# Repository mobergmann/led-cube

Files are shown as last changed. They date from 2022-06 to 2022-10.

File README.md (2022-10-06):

# led-cube

This repository contains:
1. main program: program that runs on the Pi, loads the configuration, and controls the LEDs
2. editor: program to create configuration by yourself
3. assets: files that are relevant for building the cubes
4. documentation: guide on how to assemble the cube, how to compile and install and use the main program and the editor

The documentation can be found in the `doc` folder.
A good entry point to the documentation is the [`doc/README.md`](./doc/README.md) file.

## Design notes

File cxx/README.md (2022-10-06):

# Main Program

## Dependencies
These dependencies must be installed to compile the project
- libgpiod-dev
- cmake
- g++

## Install
For an installation guide see the [documentation](../doc/README.md#compile--install).

## Pins
### User Pins
A list of pins available to the user.
The order of this list represents the available pins from top to bottom.
- 8
- 7
- 2 (does not work)
- 3 (does not work)
- 4
- 11
- 5
- 6
- 19
- 26
- 16

### Assignment
| Designation | Pin | Power-on Pull | Location |
|---|-----|---|---|
| Datain | 12 | Pull Down | Installed |
| Special Pin | 13 | Pull Down | Built-in |
| Shift Clock | 14 | Pull Down | Built-in |
| Store Clock | 15 | Pull Down | Built |
| Reset Pin | 18 | Pull Down | Built |
| Layer 1 | 20 | Pull Down | Built |
| Layer 2 | 21 | Pull Down | Built |
| Layer 3 | 23 | Pull Down | Built |
| Layer 4 | 24 | Pull Down | Built |
| Layer 5 | 25 | Pull Down | Built |
| Pairing LED | 11 | Pull Down | User Pins |
| Bluetooth Button | 6 | Pull Up | User Pins |
| Next Button | 4 | Pull Up | User Pins |
| Previous Button | 5 | Pull Up | User Pins |
| Power Button | 7 | Pull Up | User Pins |

## Program
### file format
The configurations are in [JSON](https://www.json.org/json-de.html) format.  
Each frame is specified with the time to be displayed.  
The data is specified as a 3D array.

For example, a configurations that causes the cube to light up fully for one second and then remain dark for one second might look like the following:
```json
{
  "frames": [
    {
      "frame-time": 1000,
      "layers": [
        [
          [true, true, true, true, true],
          [true, true, true, true, true],
          [true, true, true, true, true],
          [true, true, true, true, true],
          [true, true, true, true, true]
        ],
        [
          [true, true, true, true, true],
          [true, true, true, true, true],
          [true, true, true, true, true],
          [true, true, true, true, true],
          [true, true, true, true, true]
        ],
        [
          [true, true, true, true, true],
          [true, true, true, true, true],
          [true, true, true, true, true],
          [true, true, true, true, true],
          [true, true, true, true, true]
        ],
        [
          [true, true, true, true, true],
          [true, true, true, true, true],
          [true, true, true, true, true],
          [true, true, true, true, true],
          [true, true, true, true, true]
        ],
        [
          [true, true, true, true, true],
          [true, true, true, true, true],
          [true, true, true, true, true],
          [true, true, true, true, true],
          [true, true, true, true, true]
        ]
      ]
    },
    {
      "frame-time": 1000,
      "layers": [
        [
          [false, false, false, false, false],
          [false, false, false, false, false],
          [false, false, false, false, false],
          [false, false, false, false, false],
          [false, false, false, false, false]
        ],
        [
          [false, false, false, false, false],
          [false, false, false, false, false],
          [false, false, false, false, false],
          [false, false, false, false, false],
          [false, false, false, false, false]
        ],
        [
          [false, false, false, false, false],
          [false, false, false, false, false],
          [false, false, false, false, false],
          [false, false, false, false, false],
          [false, false, false, false, false]
        ],
        [
          [false, false, false, false, false],
          [false, false, false, false, false],
          [false, false, false, false, false],
          [false, false, false, false, false],
          [false, false, false, false, false]
        ],
        [
          [false, false, false, false, false],
          [false, false, false, false, false],
          [false, false, false, false, false],
          [false, false, false, false, false],
          [false, false, false, false, false]
        ]
      ]
    }
  ]
}
```

In the input there must be an attribute of type array, which has the name `frames`.
This holds a set of frame objects.

Each frame object has an integer attribute `frame-time`. This specifies in milliseconds how long the frame should be visible.

In the attribute `layers` is a 3D array, of size 5x5x5.  
The first dimension represents the layers (the layers from bottom to top).
Each layer, thus the second dimension, consists of 5 so-called lines.
Each line consists of 5 boolean values. 
These code whether an LED should be on or off.

The LED at the position 'layers[1][2][3]` thus represents the LED that is in the first layer (from bottom to top), in the second line (from front to back) and in the third position (from left to right).

### Loading configurations
The configuration (the `json` files) that a user wants to display in the cube must be present in the folder `~/.led-cube/custom`.

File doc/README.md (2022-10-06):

# Documentation
This is the documentation for the 3D LED Cube.
Here is documented how to assemble the cube, the assets needed for it, how to compile the program and install it on the cube, how to use the editor, and how to use the cube.

## Assets
For the assembly, a few assets are needed, which are summarized here.

### PCB
In the `assets/PCB` folder is the KiCad files for the PCB. 
You will need to have this made/ordered.

### 3D Print
In the `assets/3D-Print` folder are the STL files for the cube exterior.
You will need to have these printed.

## Assemble
See the [`assemble.md` file](./assemble.md) for more information on how to assemble the cube.

## Main Program
The "Main Program" is the program that runs continuously on the Pi to respond to I/O input from the buttons and to display the current configuration frame by frame.

### Buttons Function
There are several buttons.
- **Sync Button**: The Sync button persistently loads files from an inserted USB stick into the internal memory.
  If files have the same name as files that are already on the cube, they will be overwritten.
  The LED next to the Sync button will blink to indicate how long the transfer will take (this should not take too long).
- **Previous-/ Next Button**: The Previous and Next button toggles between the configurations it has stored.
  Previous toggles back one configuration and Next toggles forward one configuration.
- **On/ Off Button**: Turns off the LEDs, but continues to simulate the frames.
- **Reset Button**: The Reset Button is a special button, whose functionality can only be obtained by pressing the *Sync Button* for a long time - at least 3 seconds.
Then the current configuration is deleted from the persistent storage and the next program is loaded. Only configurations uploaded by the user can be deleted, and pre-installed programs cannot be deleted.

### Compile & Install
To make the installation as easy as possible we have added a few scripts in the `cxx/install/` folder.
1. build script
2. install script

If you dont want to compile the program you can simply download a Release, unzip it into the USB and continue with the *Install* step.

If you want to compile the program yourself you need a Pi with internet access because you have to compile it for the operating system and architecture of the Pi.
You can also compile the code without a Pi with the right tools, but this is relatively complex and will not be explained here.
If you still want to try to compile *without Pi* or *without internet access*, you should know that you need the `libgpiod2` dependency for the *main program* and the `libgpiod-dev` dependency *for compilation*.

#### Build
But if you use the Pi, you can simply clone the repo (with the submodules) and run the `cxx/build/build.sh` script.
Make sure you have a USB stick plugged into the compile pi and confirm during the script if you want the files to be written to the stick with yes.
If your USB stick cannot be found, then it can be because it is not accessible under the `/dev/sda1` path.
In this case, you can change the path from `/dev/sda1` to your path in the script.

#### Install
If you have installed the programs from the build to the USB stick, then you can put the stick into your LED-Cube-Pi.
On the USB you should find a `cube/` folder, where you can also find an `install.sh` file.
You have to execute this file to install the program on the Pi.

The installation also includes the entry and activation as a system service, so that the program starts automatically when the Pi is started.

#### Commands
On the Compile-Pi run:
```bash
git clone --recurse-submodules git@github.com:mobergmann/led-cube.git
cd led-cube/cxx/install
# plug in a USB stick
./build.sh # watch out for I/O
            # enter your (sudo) password
            # press y to install to usb
```

Switch to the Cube-Pi, plug in the prepared USB, and then run:
```bash
mount /dev/sda1 /mnt
cd /mnt/cube
sudo sh install.sh
reboot
```

## Editor
See the [`/editor/README.md` file](../editor/README.md) for more information on how to compile and use the editor.

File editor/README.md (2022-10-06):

# Editor

## Dependencies

[Processing](https://processing.org/download)

[ControlP5](https://www.sojamo.de/libraries/controlP5/)

## Install ControlP5

To install ControlP5. Download ControlP5 and unzip it. Then drag it into the Sketchbook folder of Processing.
After that Processing has to be restarted.

## Program

### Cube / LED Toggle
Individual LEDs can be edited by simply clicking on them. 
The cube can also be rotated by dragging the mouse.

### New Frame
A new empty frame can be created.
This is always created under the currently selected one.

### Copy / Paste Frame
The current frame can be copied and pasted to another location.

### Delete Frame
To delete the current frame

### Frame Time
The time until the next frame can be set here. Default: 1ms

### X / Y / Z
These buttons can be used to move the current frame in one direction.

### Place / Remove RND (Random)
A random LED can be switched off or on with this button.

### Magic Button
In Processing, an individual script can be created for this purpose with which frames can be created automatically. Simply add your code in line 266 in the editor.pde file. 

### Open File
An existing .json file can be selected here. 

### File Name
Here you can edit the name of the file. Files with the same name will be overwritten. To save a file, it must have a name.

### Save File
The file is saved here. A folder must be selected beforehand in which the file will be saved.

### Frame List
Here you can switch back and forth between the individual frames. The currently selected frame is displayed in the head.

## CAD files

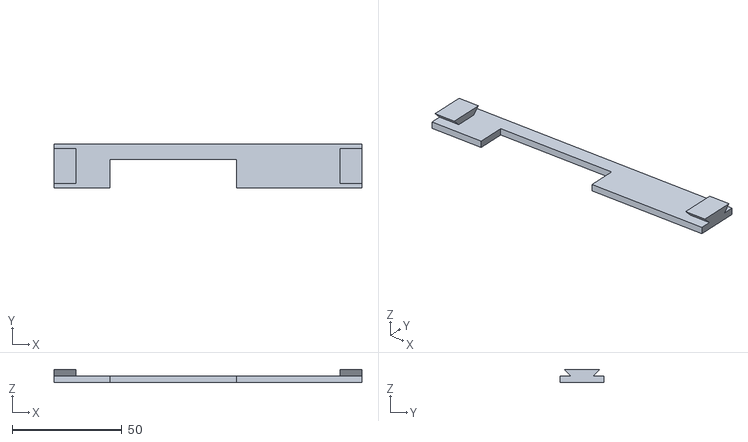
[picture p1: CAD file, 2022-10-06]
assets/3D-Print/right-side.stl
140.0 x 20.0 x 6.00

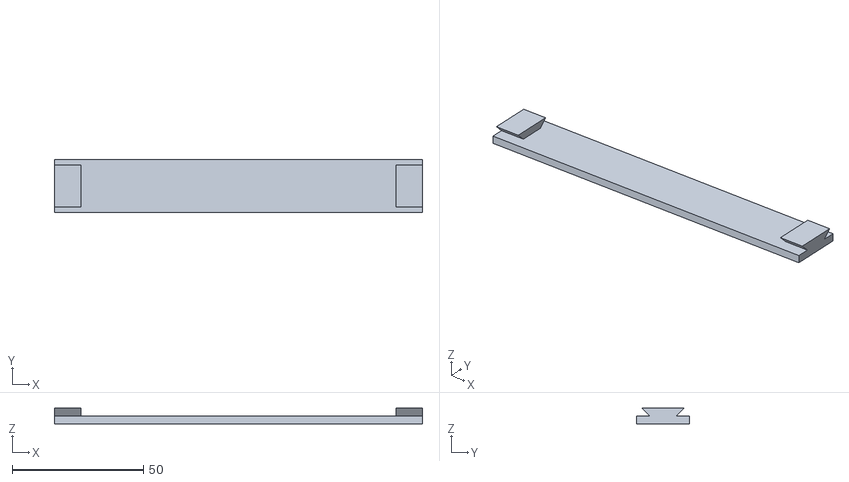
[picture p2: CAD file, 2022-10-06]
assets/3D-Print/left-side.stl
140.0 x 20.0 x 6.00

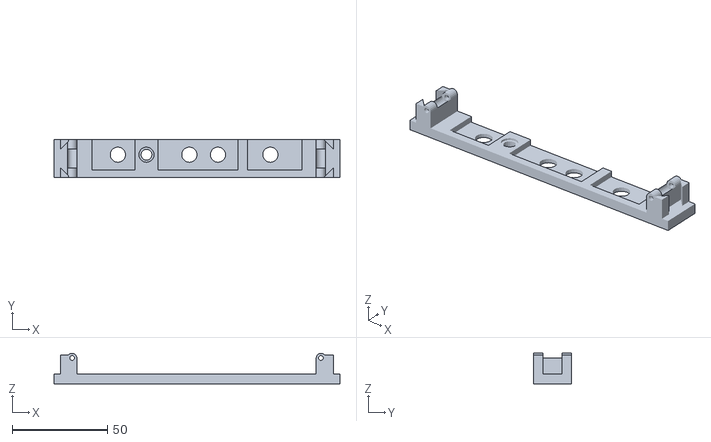
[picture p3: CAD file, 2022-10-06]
assets/3D-Print/front-side.stl
150.0 x 20.0 x 16.0

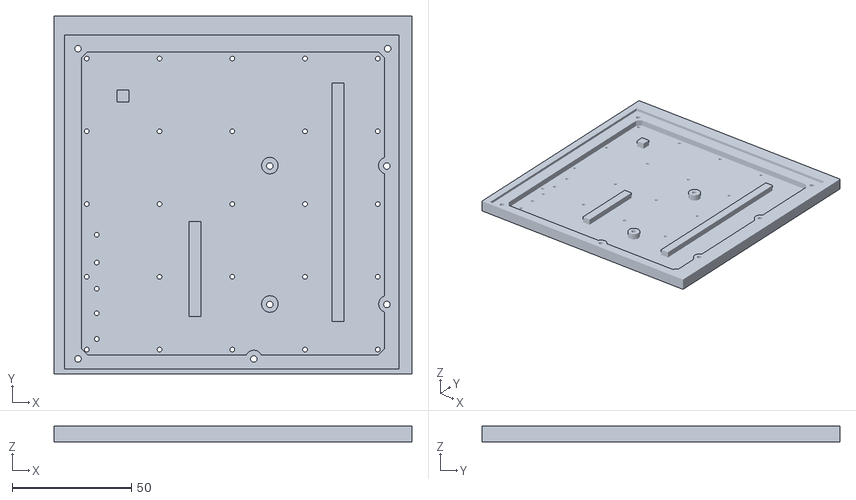
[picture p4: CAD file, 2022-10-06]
assets/3D-Print/top.stl
150.0 x 150.0 x 6.65

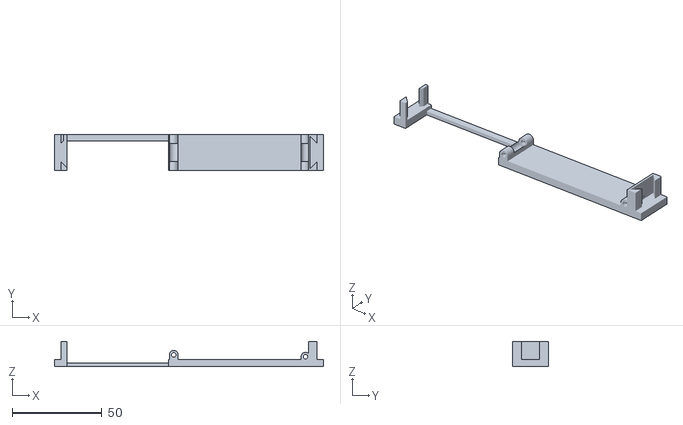
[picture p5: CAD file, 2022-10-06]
assets/3D-Print/back-side.stl
150.0 x 20.0 x 14.0

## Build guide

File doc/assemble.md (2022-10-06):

# Assemble

## Components

- Soldering iron and solder
- vice
- 1x PCB board (plan available in the appendix)
- 1x Raspberry Pi 2 or better
- 1x Micro SD card
- 125x LED 20mA, 3.3V
- 1x LED 20mA, 3.3V (different color)
- 5x rolls of wire 1.0mm
- 25x 100 Ohm resistors
- 5x 1k Ohm resistors
- 1x 10k Ohm resistors
- 3x 74HC595 shift register
- 3x matching sockets
- 3x Ceramic Disk Capacitor 0.1 microfarad
- 1x multilayer ceramic capacitor (MLCC) 220 nanofarad, 50 volts
- 1x Tantalum electrolytic capacitor 2.2 microfarad, 35 volts +
- 5x Transistor 2N2222A H331
- 5x 2N222A transistors
- 1x Female Pinheader 1x14
- 1x Male Pinheader 1x6
- 1x Female Pinheader 2x20
- 1x LF 33 CV voltage converter
- 4x Raspberry Pi spacer
- 3x Brass Spacer M2*20
- 4x Pushbuttons
- 1x plexiglass plate 30cm x 30cm
- 8x M2 screws and nuts
- ribbon cable
- (nail polish)

## Assembly

### PCB

The PCB was designed so that you can usually tell which components go where. 
Additional reference: The components come to the following places

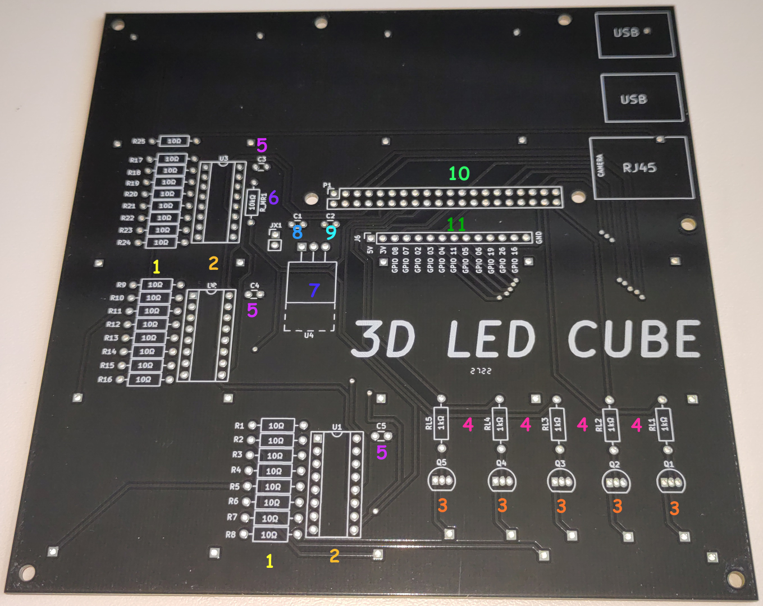
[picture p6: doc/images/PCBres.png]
PCB


1. 100 Ohm resistors
2. 74HC595 shift register and matching sockets
3. 2N222A transistors
4. 1k Ohm resistors
5. Ceramic Disk Capacitor 0.1 microfarad
6. 10k Ohm resistors
7. LF 33 CV voltage converter
8. multilayer ceramic capacitor (MLCC) 220 nanofarad, 50 volts
9. Tantalum electrolytic capacitor 2.2 microfarad, 35 volts +
10. Female Pinheader 2x20 and Raspberry Pi 2
11. Female Pinheader 1x14, Male Pinheader 1x6 for the buttons

### Wire Mesh

The wire mesh consists of 125 LEDs and a lot of wire. Each layer contains 25 LEDs connected with wire. We would recommend using a wood template or something similar. Sold 5 LEDs to a wire, make sure that you only connect the annodes OR cathodes.
Connect the LED-wires with 2 additional wires to form a square. Depending on the used LED, it might be necessary to cover the LEDs bottom with (nail) paint to avoid lower LEDs light shining through. Repeat this step 5 times.
Thread 30 wires through PCB and printed board and solder them to the PCB. Use spacers to ensure even spacing. Sold the remaining annode or cathode to the respective upwards pointing wire.
Each layer needs to be connected with it's corresponding layer wire in the back right. The most left to layer one, the most right wire to the last (upper) layer.
The image in the editor can be used as a reference.

### Buttons

3D print the case and screw the buttons and the "connection LED" to the intended places. Attach a ribbon cable to each button and one of the led wires.
Sold the male pinheader to the other ends of the ribbon cables. Use an additional wire to connect the remaining pins and connect an additional ribbon cable for ground.
Plug the male pinheader in the female pinheader as following:

- black button to GPIO 07
- green button to GPIO 04
- yellow button to GPIO 11
- LED to GPIO05
- blue button to GPIO 06
- ground wire to GND

### Last steps

Use the screws to assemble the case. Use the Plexiglas to seal the case as a see through bottom. The edge of the Plexiglas pane can be worn down so that the light of the Raspberry Pi does not show through.

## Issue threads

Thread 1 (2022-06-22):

pin enabeling is reserved

mobergmann, 2022-06-22:
the order of the pins that are activated is reversed in the main program

mobergmann, 2022-06-22:
@Seb8299 waren nur die pins pro lain verdreht, oder auch die lains?

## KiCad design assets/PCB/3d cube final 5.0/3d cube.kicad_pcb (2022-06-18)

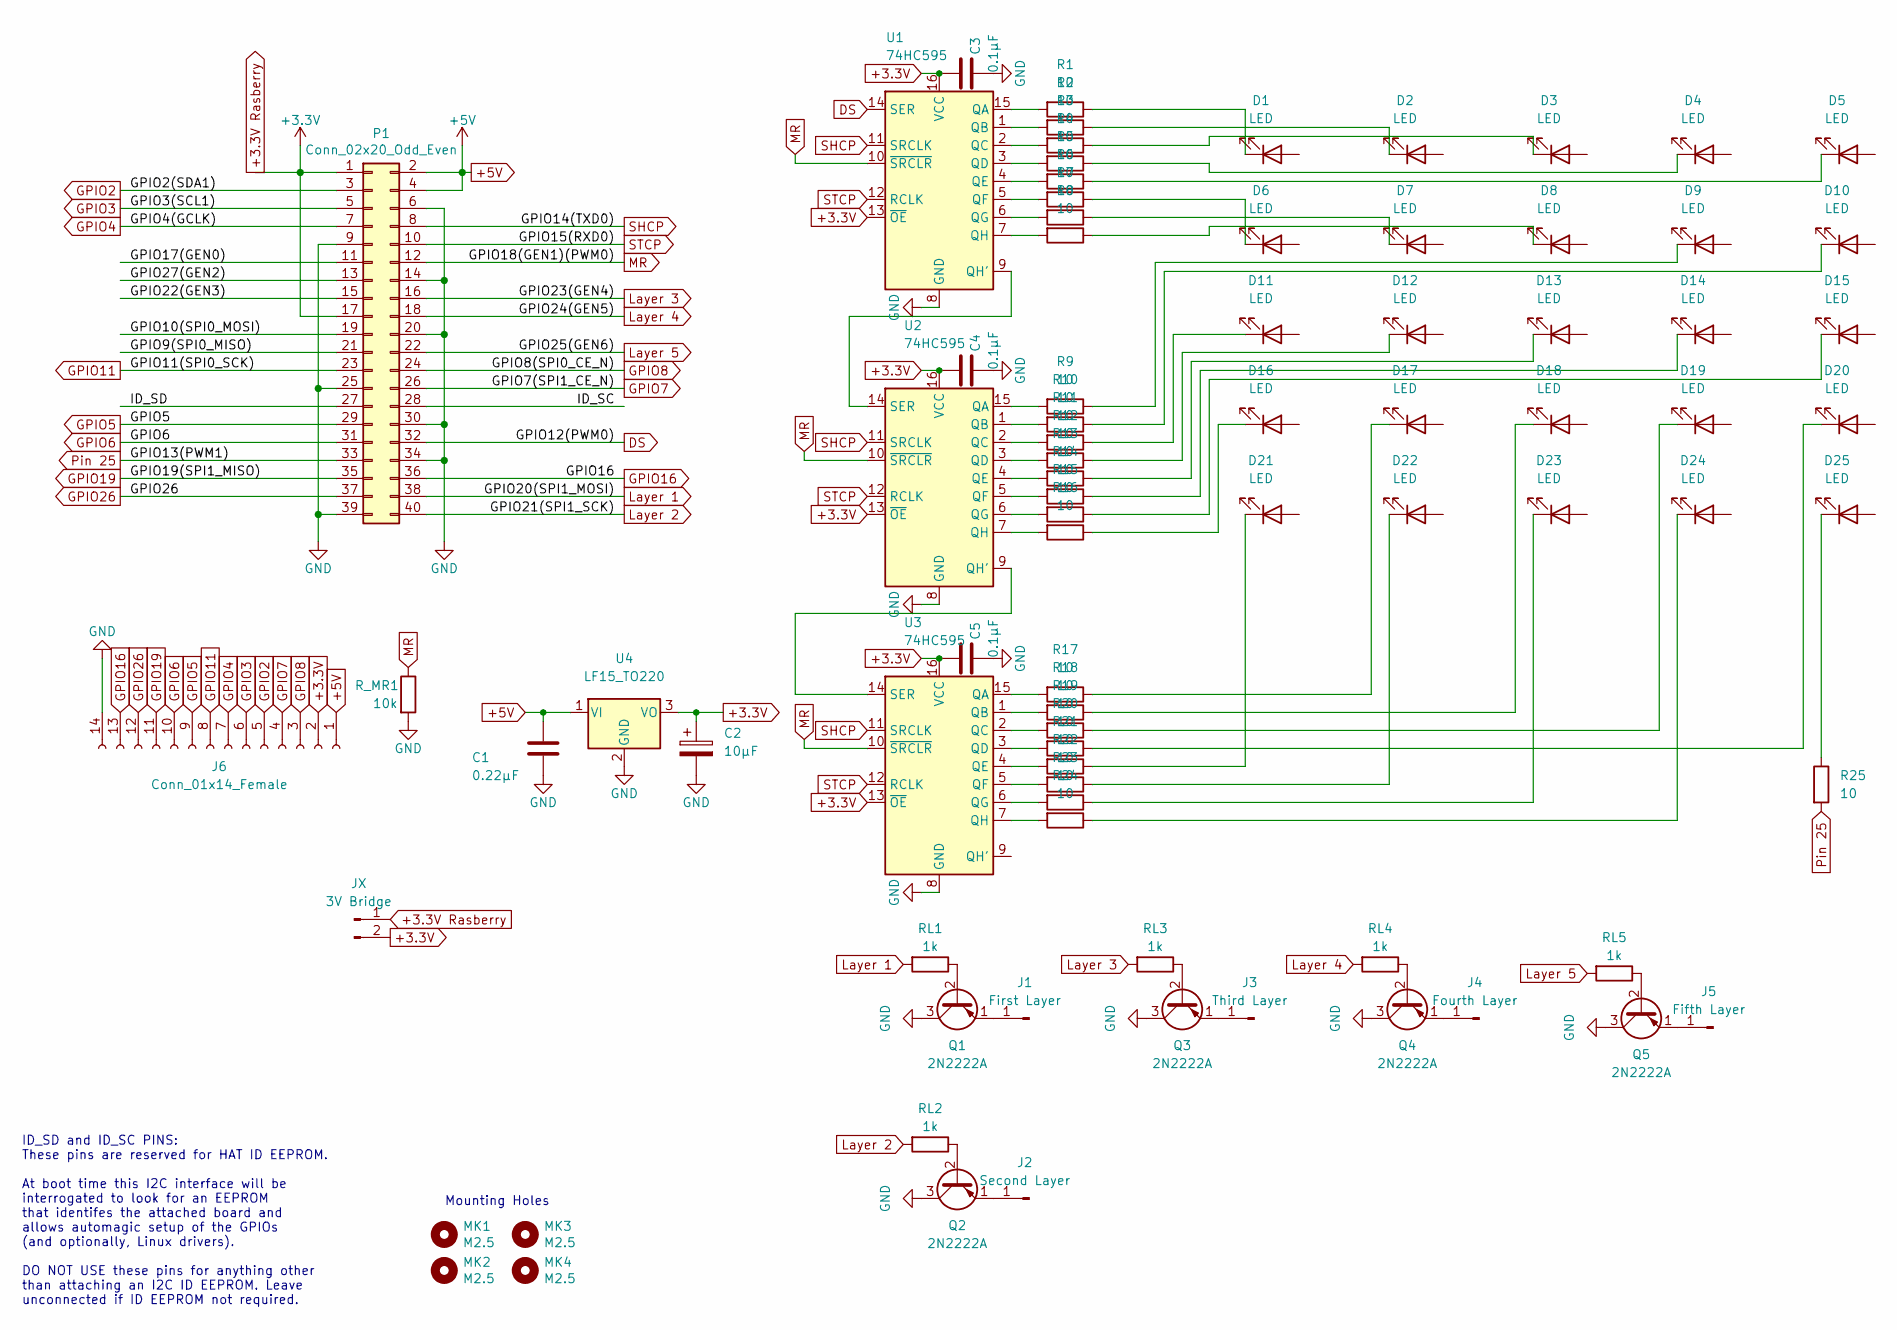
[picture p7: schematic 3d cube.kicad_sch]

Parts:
C1: 0.22μF; C_Disc_D3.0mm_W1.6mm_P2.50mm
C2: 10μF; C_Disc_D3.0mm_W1.6mm_P2.50mm
C3, C4, C5: 0.1μF; C_Disc_D3.0mm_W1.6mm_P2.50mm
D1, D2, D3, D4, D5, D6, D7, D8, D9, D10, D11, D12, D13, D14, D15, D16, D17, D18, D19, D20, D21, D22, D23, D24, D25: LED; PinSocket_1x01_P2.54mm_Vertical
J1: First Layer; PinSocket_1x01_P2.54mm_Vertical
J2: Second Layer; PinSocket_1x01_P2.54mm_Vertical
J3: Third Layer; PinSocket_1x01_P2.54mm_Vertical
J4: Fourth Layer; PinSocket_1x01_P2.54mm_Vertical
J5: Fifth Layer; PinSocket_1x01_P2.54mm_Vertical
J6: Conn_01x14_Female; PinSocket_1x14_P2.54mm_Vertical
JX: 3V Bridge; PinHeader_1x02_P2.54mm_Vertical
MK1, MK2, MK3, MK4: M2.5; MountingHole_2.7mm_M2.5
P1: Conn_02x20_Odd_Even; PinSocket_2x20_P2.54mm_Vertical
Q1, Q2, Q3, Q4, Q5: 2N2222A; TO-92_Inline
R1, R2, R3, R4, R5, R6, R7, R8, R9, R10, R11, R12, R13, R14, R15, R16, R17, R18, R19, R20, R21, R22, R23, R24, R25: 10; R_Axial_DIN0207_L6.3mm_D2.5mm_P10.16mm_Horizontal
RL1, RL2, RL3, RL4, RL5: 1k; R_Axial_DIN0207_L6.3mm_D2.5mm_P10.16mm_Horizontal
R_MR1: 10k; R_Axial_DIN0207_L6.3mm_D2.5mm_P10.16mm_Horizontal
U1, U2, U3: 74HC595; DIP-16_W7.62mm_Socket
U4: LF15_TO220; TO-220-3_Horizontal_TabUp

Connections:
+3.3V: C2.1, C3.1, C4.1, C5.1, J6.2, JX.2, U1.13 (~OE), U1.16 (VCC), U2.13 (~OE), U2.16 (VCC), U3.13 (~OE), U3.16 (VCC), U4.3 (VO); also elsewhere on the board
+3.3V Rasberry: JX.1, P1.1, P1.17; also elsewhere on the board
+5V: C1.1, J6.1, P1.2, P1.4, U4.1 (VI)
/GPIO9(SPI0_MISO): P1.21
/GPIO10(SPI0_MOSI): P1.19
/GPIO17(GEN0): P1.11
/GPIO22(GEN3): P1.15
/GPIO27(GEN2): P1.13
/ID_SC: P1.28
/ID_SD: P1.27
DS: P1.32, U1.14 (SER)
GND: C1.2, C2.2, C3.2, C4.2, C5.2, J6.14, P1.6, P1.9, P1.14, P1.20, P1.25, P1.30, P1.34, P1.39, Q1.3 (C), Q2.3 (C), Q3.3 (C), Q4.3 (C), Q5.3 (C), R_MR1.2, U1.8 (GND), U2.8 (GND), U3.8 (GND), U4.2 (GND)
GPIO2: J6.5, P1.3
GPIO3: J6.6, P1.5
GPIO4: J6.7, P1.7
GPIO5: J6.9, P1.29
GPIO6: J6.10, P1.31
GPIO7: J6.4, P1.26
GPIO8: J6.3, P1.24
GPIO11: J6.8, P1.23
GPIO16: J6.13, P1.36
GPIO19: J6.11, P1.35
GPIO26: J6.12, P1.37
Layer 1: P1.38, RL1.2
Layer 2: P1.40, RL2.2
Layer 3: P1.16, RL3.2
Layer 4: P1.18, RL4.2
Layer 5: P1.22, RL5.2
MR: P1.12, R_MR1.1, U1.10 (~SRCLR), U2.10 (~SRCLR), U3.10 (~SRCLR)
unnamed: D1.1 (K), R1.1
unnamed: D2.1 (K), R2.1
unnamed: D3.1 (K), R3.1
unnamed: D4.1 (K), R4.1
unnamed: D5.1 (K), R5.1
unnamed: D6.1 (K), R6.1
unnamed: D7.1 (K), R7.1
unnamed: D8.1 (K), R8.1
unnamed: D9.1 (K), R9.1
unnamed: D10.1 (K), R10.1
unnamed: D11.1 (K), R11.1
unnamed: D12.1 (K), R12.1
unnamed: D13.1 (K), R13.1
unnamed: D14.1 (K), R14.1
unnamed: D15.1 (K), R15.1
unnamed: D16.1 (K), R16.1
unnamed: D17.1 (K), R17.1
unnamed: D18.1 (K), R18.1
unnamed: D19.1 (K), R19.1
unnamed: D20.1 (K), R20.1
unnamed: D21.1 (K), R21.1
unnamed: D22.1 (K), R22.1
unnamed: D23.1 (K), R23.1
unnamed: D24.1 (K), R24.1
unnamed: D25.1 (K), R25.1
unnamed: J1.1, Q1.1 (E)
unnamed: J2.1, Q2.1 (E)
unnamed: J3.1, Q3.1 (E)
unnamed: J4.1, Q4.1 (E)
unnamed: J5.1, Q5.1 (E)
unnamed: Q1.2 (B), RL1.1
unnamed: Q2.2 (B), RL2.1
unnamed: Q3.2 (B), RL3.1
unnamed: Q4.2 (B), RL4.1
unnamed: Q5.2 (B), RL5.1
unnamed: R1.2, U1.15 (QA)
unnamed: R2.2, U1.1 (QB)
unnamed: R3.2, U1.2 (QC)
unnamed: R4.2, U1.3 (QD)
unnamed: R5.2, U1.4 (QE)
unnamed: R6.2, U1.5 (QF)
unnamed: R7.2, U1.6 (QG)
unnamed: R8.2, U1.7 (QH)
unnamed: R9.2, U2.15 (QA)
unnamed: R10.2, U2.1 (QB)
unnamed: R11.2, U2.2 (QC)
unnamed: R12.2, U2.3 (QD)
unnamed: R13.2, U2.4 (QE)
unnamed: R14.2, U2.5 (QF)
unnamed: R15.2, U2.6 (QG)
unnamed: R16.2, U2.7 (QH)
unnamed: R17.2, U3.15 (QA)
unnamed: R18.2, U3.1 (QB)
unnamed: R19.2, U3.2 (QC)
unnamed: R20.2, U3.3 (QD)
unnamed: R21.2, U3.4 (QE)
unnamed: R22.2, U3.5 (QF)
unnamed: R23.2, U3.6 (QG)
unnamed: R24.2, U3.7 (QH)
unnamed: U1.9 (QH'), U2.14 (SER)
unnamed: U2.9 (QH'), U3.14 (SER)
Pin 25: P1.33, R25.2
SHCP: P1.8, U1.11 (SRCLK), U2.11 (SRCLK), U3.11 (SRCLK)
STCP: P1.10, U1.12 (RCLK), U2.12 (RCLK), U3.12 (RCLK)

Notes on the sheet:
ID_SD and ID_SC PINS: These pins are reserved for HAT ID EEPROM. At boot time this I2C interface will be interrogated to look for an EEPROM that identifes the attached board and allows automagic setup of the GPIOs (and optionally, Linux drivers). DO NOT USE these pins for anything other than attach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
Mounting Holes

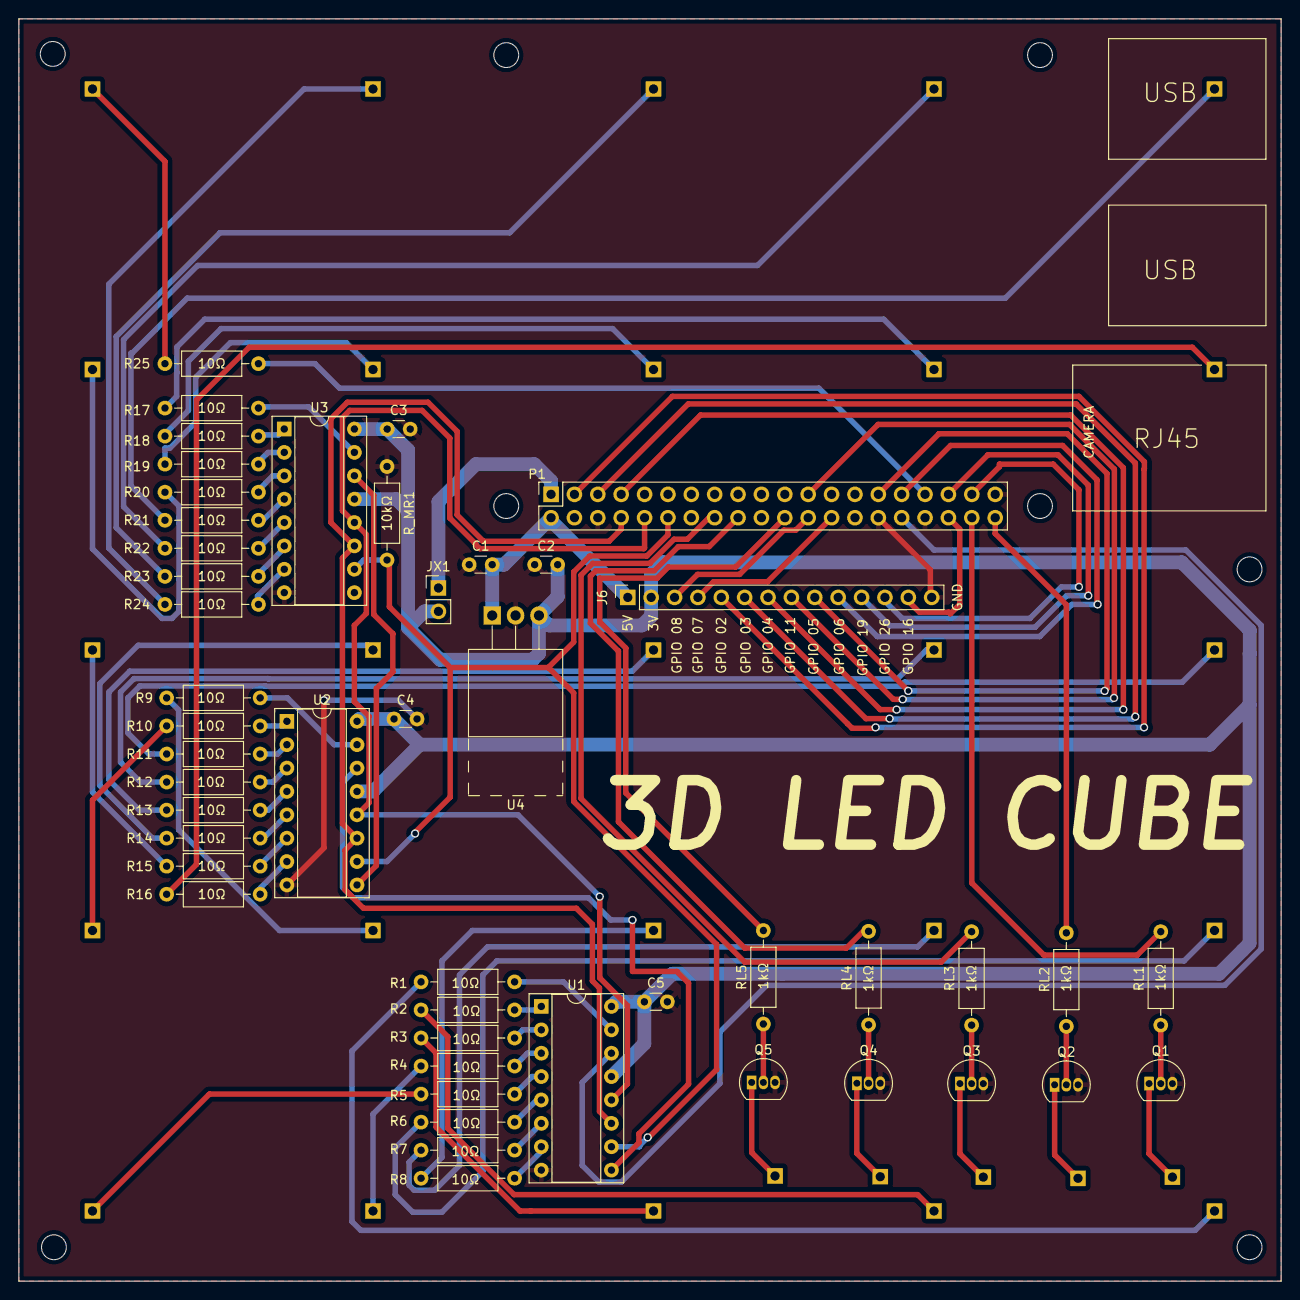
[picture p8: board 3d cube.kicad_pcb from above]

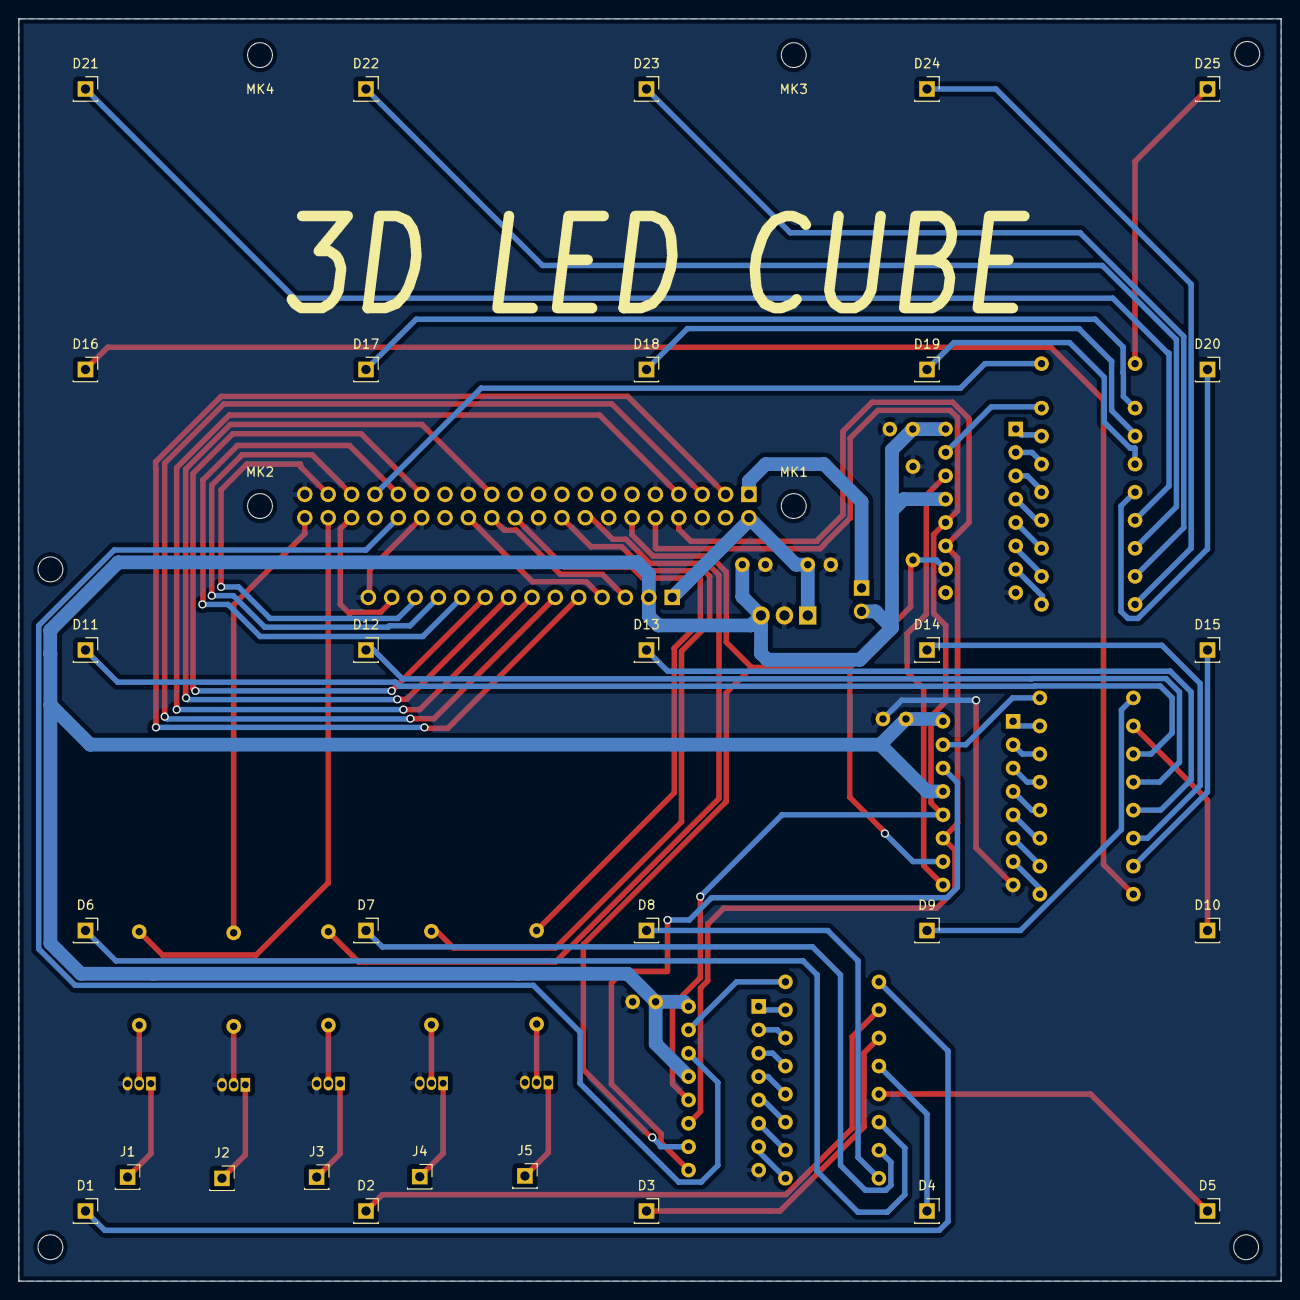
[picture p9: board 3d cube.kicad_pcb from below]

Board: 2 copper layers, 137.2 x 137.2 mm, 82 parts (34 on the bottom side), 86 nets.

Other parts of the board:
JX1: 3V Bridge; PinHeader_1x02_P2.54mm_Vertical

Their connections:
+3.3V: JX1.2; also elsewhere on the board
+3.3V Rasberry: JX1.1; also elsewhere on the board

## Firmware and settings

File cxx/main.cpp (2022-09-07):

// System Libraries
#include <array>
#include <chrono>
#include <thread>
#include <fstream>
#include <iostream>
#include <algorithm>
#include <algorithm>
#include <exception>
#include <filesystem>
// Dependencies
#include <gpiod.hpp>
#include <nlohmann/json.hpp>
// Files
#include "include/Button.h"
#include "include/Frame.h"
#include "include/FileTransfer.h"


namespace fs = std::filesystem;


class Main
{
private:
    /// a list of frames, each representing a current state of the cube
    std::vector<Frame> frames;

    /// boolean indicating if the led cube should be on
    bool cube_on;

#pragma region file management
    /// a list of all files in the data folder
    std::vector<std::string> files;

    /// stores the current configuration file
    std::string current_file;
#pragma endregion

#pragma region lines
    /// reference to the lines chip
    gpiod::chip chip;

    /// pins for each layer toggle
    std::array<gpiod::line, 5> layers;

#pragma region led
    /// reset pin
    gpiod::line pin_reset;

    /// shift clock pin
    gpiod::line pin_shift;

    /// store clock pin
    gpiod::line pin_store;

    /// datain pin
    gpiod::line pin_datain;

    /// special pin, which cannot be accessed by shifting
    gpiod::line pin_special;
    /// the value for the special pin, which needs to be applied in the store method
    bool pin_special_val;
#pragma endregion

#pragma region I/O
    /// led for showing if the cube is in pairing mode
    gpiod::line line_blink_led;

    /// button for pulling new data from usb
    Button *line_usb;

    /// button for iterating to next led setting
    Button *line_next;

    /// button for iterating to previous led setting
    Button *line_previous;

    /// button for enabling/ disabling the cube
    Button *line_power;
#pragma endregion
#pragma endregion

public:
    Main() : cube_on(true), pin_special_val(false)
    {
        // create all folders
        init_fs();

        // get all files
        update_file_list();

        // parse input data
        parse_layout();

        // init chip
        chip = gpiod::chip("gpiochip0", gpiod::chip::OPEN_BY_NAME);

#pragma region aquire lines
#pragma region layers
        // save layers to array
        layers = {
            chip.get_line(20),
            chip.get_line(21),
            chip.get_line(23),
            chip.get_line(24),
            chip.get_line(25)
        };

        // initialize layers
        for (auto &layer: layers)
        {
            layer.request({layer.name(), gpiod::line_request::DIRECTION_OUTPUT, 0}, 0);
        }
        std::cout << "All Layers acquired" << std::endl;
#pragma endregion

#pragma region led
        // reset pin setup (pull down)
        pin_reset = chip.get_line(18);
        pin_reset.request({pin_reset.name(), gpiod::line_request::DIRECTION_OUTPUT, 0}, 1);
        std::cout << "Reset pin acquired" << std::endl;

        // shift pin setup (pull down)
        pin_shift = chip.get_line(14);
        pin_shift.request({pin_shift.name(), gpiod::line_request::DIRECTION_OUTPUT, 0}, 0);
        std::cout << "Shift pin acquired" << std::endl;

        // store pin setup (pull down)
        pin_store = chip.get_line(15);
        pin_store.request({pin_store.name(), gpiod::line_request::DIRECTION_OUTPUT, 0}, 0);
        std::cout << "Store pin acquired" << std::endl;

        // datain pin setup (pull down)
        pin_datain = chip.get_line(12);
        pin_datain.request({pin_datain.name(), gpiod::line_request::DIRECTION_OUTPUT, 0}, 0);
        std::cout << "Datain pin acquired" << std::endl;

        // special pin setup (pull down)
        pin_special = chip.get_line(13);
        pin_special.request({pin_special.name(), gpiod::line_request::DIRECTION_OUTPUT, 0}, 0);
        std::cout << "Special pin acquired" << std::endl;
#pragma endregion

#pragma region I/O
        // Pairing Mode LED (pull down)
        line_blink_led = chip.get_line(11);
        line_blink_led.request({line_blink_led.name(), gpiod::line_request::DIRECTION_OUTPUT, 0}, 0);
        std::cout << "Pairing Mode LED acquired" << std::endl;

        /// button for pulling from usb
        line_usb = new Button(chip, 6);
        std::cout << "bluetooth pairing pin acquired" << std::endl;

        /// button for iterating to next led setting
        line_next = new Button(chip, 4);
        std::cout << "Previous setting pin acquired" << std::endl;

        /// button for iterating to previous led setting
        line_previous = new Button(chip, 5);
        std::cout << "Next setting pin acquired" << std::endl;

        /// button for enabling/ disabling the cube
        line_power = new Button(chip, 7);
        std::cout << "power on/ off pin acquired" << std::endl;
#pragma endregion
#pragma endregion
    }

    ~Main()
    {
        delete line_usb;
        delete line_previous;
        delete line_next;
        delete line_power;
    }

private:
    void init_fs()
    {
        // create directories if not existent
        if (not fs::exists(FileTransfer::default_path))
        {
            fs::create_directories(FileTransfer::default_path);
        }

        // create directories if not existent
        if (not fs::exists(FileTransfer::custom_path))
        {
            fs::create_directories(FileTransfer::custom_path);
        }
    }

    void parse_layout()
    {
        std::vector<Frame> _frames;

        // load from file
        std::ifstream stream(current_file);

        nlohmann::json file;
        stream >> file;

        // parse json
        for (auto &_frame: file["frames"])
        {
            Frame frame{};

            // frame time
            frame.frame_time = _frame["frame-time"];

            // layer data
            for (int i = 0; i < 5; ++i)
            {
                for (int j = 0; j < 5; ++j)
                {
                    for (int k = 0; k < 5; ++k)
                    {
                        const auto &value = _frame["layers"][i][j][k];
                        frame.data[i][j][k] = value;
                    }
                }
            }

            _frames.push_back(frame);
        }

        frames = _frames;
    }

#pragma region line controll abstraction methods
    void reset()
    {
        pin_reset.set_value(0);
        pin_reset.set_value(1);

        // set special pin for turn off on store
        pin_special_val = false;
    }

    void shift()
    {
        pin_shift.set_value(1);
        pin_shift.set_value(0);
    }

    void store()
    {
        // actually turn of reset pin
        if (pin_special_val)
        {
            pin_special.set_value(1);
        }
        else
        {
            pin_special.set_value(0);
        }

        pin_store.set_value(1);
        pin_store.set_value(0);
    }
#pragma endregion

    void update_file_list()
    {
        std::string tmp = current_file;

        files.clear();

        // search all new files

        // add default cube configurations
        for (const auto &file: fs::recursive_directory_iterator(FileTransfer::default_path))
        {
            std::cout << "Found file: " << file.path() << std::endl;
            files.push_back(file.path());
        }
        // add custom cube configurations
        for (const auto &file: fs::recursive_directory_iterator(FileTransfer::custom_path))
        {
            std::cout << "Found file: " << file.path() << std::endl;
            files.push_back(file.path());
        }

        // search element in list, if not exits use fallback option
        current_file = files[0]; // fallback option
        for (const auto &val: files)
        {
            if (val == tmp)
            {
                current_file = val;
                break;
            }
        }
    }

    void del()
    {
        // if only one or fewer elements in list => no save deletion possible
        if (files.size() <= 1)
        {
            std::cout << "Only one config present: " << std::endl;
            return;
        }

        // if file is in default dir, then it cannot be deleted
        if (current_file.starts_with(FileTransfer::default_path.string()))
        {
            // todo use cerr
            std::cout << "File cannot be deleted, because it is in default dir" << std::endl;
            return;
        }

        // search element in list, if not exits use fallback option
        std::string tmp = current_file;

        // set current file to next elem
        next();

        try
        {
            fs::remove(tmp);
        }
        catch (std::exception &e)
        {
            // todo use cerr
            std::cout << "Error while deleting file: " << e.what() << std::endl;
            return;
        }

        std::cout << "New Configuration: " << current_file << std::endl;
    }

    void next()
    {
        // if only one or fewer elements in list => no scrolling possible
        if (files.size() <= 1)
        {
            std::cout << "Only one config present: " << std::endl;
            return;
        }

        // search element in list, if not exits use fallback option
        std::string tmp = current_file;
        current_file = files[0]; // fallback option
        for (int i = 0; i < files.size(); ++i)
        {
            const auto &it = files[i];

            if (it == tmp)
            {
                // when at end, the next element is the beginning of the list
                if (i == files.size()-1)
                {
                    // current_file = files[0]; // this is the fallback option, therefore change nothing
                }
                // when found use previous element as new one
                else
                {
                    current_file = files[i+1];
                }
                break;
            }
        }
        std::cout << "New Configuration: " << current_file << std::endl;
    }

    void previous()
    {
        // if only one or fewer elements in list => no scrolling possible
        if (files.size() <= 1)
        {
            std::cout << "Only one config present: " << std::endl;
            return;
        }

        // search element in list, if not exits use fallback option
        std::string tmp = current_file;
        current_file = files[0]; // fallback option
        for (int i = 0; i < files.size(); ++i)
        {
            const auto &it = files[i];

            if (it == tmp)
            {
                // when at beginning, the previous element is the beginning of the list
                if (i == 0)
                {
                    current_file = files[files.size()-1];
                }
                // when found use previous element as new one
                else
                {
                    current_file = files[i-1];
                }
                break;
            }
        }
        std::cout << "New Configuration: " << current_file << std::endl;
    }

    /**
     * Polls for button events and then process these events
     * @return true if one of the next or previous buttons have been pressed.
     */
    bool poll()
    {
        bool skip_frame_flag = false;

        line_usb->poll([&](){
                std::cout << "file transfer button pressed" << std::endl;
                try
                {
                    FileTransfer::copy(&line_blink_led);
                }
                catch (const std::runtime_error &e)
                {
                    std::cerr << "Error while transferring: " << e.what() << std::endl;
                }

                // update the file, to load newly added files
                update_file_list();
            },
            std::chrono::milliseconds(3000), [&](){
                std::cout << "delete button triggered" << std::endl;

                del();
                update_file_list();
                parse_layout();

                skip_frame_flag = true;
            }
        );

        line_previous->poll([&]()
        {
            std::cout << "previous setting button press" << std::endl;

            previous();
            parse_layout();

            skip_frame_flag = true;
        });

        line_next->poll([&](){
            std::cout << "next setting button press" << std::endl;

            next();
            parse_layout();

            skip_frame_flag = true;
        });

        line_power->poll([&](){
            std::cout << "switch on/ off button press" << std::endl;

            reset();
            store();

            cube_on = not cube_on;
        });

        return skip_frame_flag;
    }

    void set_leds(const layers_t &frame_data)
    {
        if (not cube_on)
        {
            return;
        }

        for (int i = 0; i < frame_data.size(); ++i)
        {
            // reset all leds for next frame
            reset();

            for (int j = frame_data[i].size()-1; j >= 0; --j)
            {
                for (int k = frame_data[i][j].size()-1; k >= 0; --k)
                {
                    const auto led_value = frame_data[i][k][j];

                    // turn on special pin if end of shift register reached (layer 5 and pin 25)
                    if (j == 4 && k == 4)
                    {
                        pin_special_val = led_value;
                    }
                    else
                    {
                        pin_datain.set_value(led_value);
                        shift(); // only shift, when not the last pin
                    }
                }
            }

            // disable previous layer (no more than one layer is allowed to be on)
            if (i == 0) // if at the beginning of the array disable previous layer
            {
                layers[frame_data.size()-1].set_value(0);
            }
            else
            {
                layers[i-1].set_value(0);
            }

            store(); // store each layer

            // enable current layer
            layers[i].set_value(1);
        }
    }

public:
    void loop()
    {
        for (auto &frame: frames)
        {
            // timer is used to determine if we should switch to next frame
            const auto starting_time = std::chrono::steady_clock::now();
            // convert the frame time to milliseconds
            const auto max_frame_time = std::chrono::milliseconds(frame.frame_time);

            // replay current frame as fast as possible, as often as possible
            // and only at the end of the current frame duration continue with next frame
            while (true)
            {
                // poll for possible button events
                if (poll())
                {
                    return;
                }

                set_leds(frame.data);

                // break loop, only if the elapsed time is larger than the max frame time
                auto current_time = std::chrono::steady_clock::now();
                auto elapsed_time =
                    std::chrono::duration_cast<std::chrono::milliseconds>(current_time - starting_time);
                if (elapsed_time >= max_frame_time)
                {
                    goto break_while;
                }
            }
            break_while:;
        }
    }
};

int main()
{
    try 
    {
        Main m;
        while (true)
        {
            m.loop();
        }
    }
    catch(const std::exception& e) 
    {
        std::cerr << "failure: " << e.what() << std::endl;
    }
}

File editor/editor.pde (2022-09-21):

import controlP5.*;

// UI
ControlP5 cp5;

ScrollableList frameList;
Button newFrameButton;
Button deleteFrameButton;
Button saveFileButton;
Button openFileButton;
Button playButton;
Textfield frameTimeTf;
Textfield fileNameTf;
Button pushX;
Button popX;
Button pushY;
Button popY;
Button pushZ;
Button popZ;
Button copy;
Button paste;

// play sequence
boolean playSequence = false;
int time = millis();

// rotation
float xpos= 0;
float ypos= 0;
float zpos= 0;

// mouse values for rotation
int last_mouseX = 0;
int last_mouseY = 0;

// frames
ArrayList<Cube> frames = new ArrayList<Cube>();
int selectedFrame;
Cube copyFrame = new Cube();

void setup() {
  // meta setup
  size(1250, 780, P3D);
  surface.setResizable(true);  
  
  UI();
  
  // initial frame
  frames.add(new Cube());
  selectedFrame = 0;
  
  updateFrames();
}

void draw() {
  background(50);
  lights();
  
  // cube
  pushMatrix();
  
  translate(width*3/5, height/2-70,0);
  rotateX(xpos+1.56-0.3);
  rotateY(ypos+0.64-PI/5);
  rotateZ(zpos);
  
  frames.get(selectedFrame).update();
  
  popMatrix();
  
  // making toggle cube ## experimental
  //pushMatrix();
  
  //translate(width-60, height-60, 0);
  //rotateX(xpos+1.56-0.3);
  //rotateY(ypos+0.64-PI/5);
  //rotateZ(zpos);
  
  //fill(255, 255, 255, 150);
  //box(40);
  //translate(-20, -20, 0);
  //fill(255, 0, 0);
  //box(10, 10, 40);
  //translate(0, 0, -20);
  //rotateX(PI/2);
  //box(15, 15, 15);
  
  //popMatrix();
  
  // cube rotation
  frames.get(selectedFrame).cubeMoving(false);
  
  if (mousePressed && !frames.get(selectedFrame).LedSelected()) { 
    frames.get(selectedFrame).cubeMoving(true);
    
    float orbitRadius= (last_mouseX-mouseX)/2;
    xpos += (float(last_mouseY-mouseY)/3)/100;
    zpos += (cos(radians(0))*orbitRadius)/100;
    ypos = (sin(radians(0))*orbitRadius)/100;
  }
  
  last_mouseX = mouseX;
  last_mouseY = mouseY;
  
  // handle play button
  try {
    if (playSequence) {
      if (millis()-time >= int(frameTimeTf.getText())) {
        selectedFrame++;
        selectedFrame = selectedFrame % frames.size();
        time = millis();
        updateFrames();
      }
    }
  }
  catch(Exception e) {}
  
  
  frameList.setSize(150, height-5);
  fileNameTf.setPosition(5, height-55);
  saveFileButton.setPosition(5, height-105);
  openFileButton.setPosition(5, height-155);
}

// UI
void UI() {
  cp5 = new ControlP5(this);
  var arial = createFont("arial",20);
  
  // ListVIew for the frame
  
  frameList = cp5.addScrollableList("Layers")
     .setPosition(165, 5)
     .setSize(150, height-5)
     .setBarHeight(40)
     .setItemHeight(30)
     .onRelease(new CallbackListener() {
  public void controlEvent(CallbackEvent theEvent) {
    frameList.setOpen(true);
    
    if (playSequence)
      return;
    
    selectedFrame = (int)frameList.getValue();
    }
  });
  
  // new frame button
  newFrameButton = cp5.addButton("New Frame")
     .setValue(0)
     .setPosition(5, 5)
     .setSize(150,40)
     .onRelease(new CallbackListener() {
  void controlEvent(CallbackEvent theEvent) {
    
      if (playSequence)
        return;
        
      selectedFrame++;
      frames.add(selectedFrame, new Cube());
      updateFrames();
    }
  });
  
  // delete frame button
  deleteFrameButton = cp5.addButton("Delete Frame")
     .setValue(0)
     .setPosition(5, 105)
     .setSize(150,40)
     .onRelease(new CallbackListener() {
    void controlEvent(CallbackEvent theEvent) {
      
      if (playSequence)
        return;
        
      frames.remove(frames.get(selectedFrame));
      
      if (selectedFrame >= frames.size()) {
        selectedFrame = frames.size()-1;
      }
      if (frames.size() == 0) {
        frames.add(new Cube());
        selectedFrame = 0;
      }
      updateFrames();
    }
  });
     
  // copy frame button
  copy = cp5.addButton("Copy Frame")
     .setValue(0)
     .setPosition(5, 55)
     .setSize(70,40)
     .onRelease(new CallbackListener() {
    void controlEvent(CallbackEvent theEvent) {
      if (playSequence)
        return;
        
      copyFrame = new Cube(frames.get(selectedFrame));
    }
  });
     
  // paste frame button
  paste = cp5.addButton("Paste Frame")
     .setValue(0)
     .setPosition(85, 55)
     .setSize(70,40)
     .onRelease(new CallbackListener() {
    void controlEvent(CallbackEvent theEvent) {
      if (playSequence)
        return;
        
      selectedFrame++;
      frames.add(selectedFrame, new Cube(copyFrame));
      updateFrames();
    }
  });
     
  // place random button
  paste = cp5.addButton("Place RND")
     .setValue(0)
     .setPosition(5, 360)
     .setSize(70,40)
     .onRelease(new CallbackListener() {
    void controlEvent(CallbackEvent theEvent) {
      if (playSequence)
        return;
        
      frames.get(selectedFrame).placeRnd();
    }
  });
     
  // remove random button
  paste = cp5.addButton("Remove RND")
     .setValue(0)
     .setPosition(85, 360)
     .setSize(70,40)
     .onRelease(new CallbackListener() {
    void controlEvent(CallbackEvent theEvent) {
      if (playSequence)
        return;
        
      frames.get(selectedFrame).removeRnd();
    }
  });
  
  // Magic button
  paste = cp5.addButton("Magic Button")
     .setValue(0)
     .setPosition(5, 410)
     .setSize(150,40)
     .onRelease(new CallbackListener() {
    void controlEvent(CallbackEvent theEvent) {
      if (playSequence)
        return;
        
      // magic code here
      
      
    }
  });
     
  // set frametime
  frameTimeTf = cp5.addTextfield("Frame Time (ms)")
     .setPosition(5, 155)
     .setSize(150,40)
     .setFont(arial)
     .setColor(color(255,255,255))
     .setValue("1000")
     ;
     
   // play sequence button
   playButton = cp5.addButton("Play")
     .setValue(0)
     .setPosition(5, 210)
     .setSize(150,40)
     .onRelease(new CallbackListener() {
    void controlEvent(CallbackEvent theEvent) {
      
      if (playSequence) {
        playSequence = false;
        playButton.setLabel("Play");
      }
      else {
        playSequence = true;
        playButton.setLabel("Pause");
        time = millis();
      }
    }
  });
  
  // shift cube buttons
   pushX = cp5.addButton("+X")
     .setValue(0)
     .setPosition(5, 260)
     .setSize(45,40)
     .onRelease(new CallbackListener() {
    void controlEvent(CallbackEvent theEvent) {
      frames.get(selectedFrame).shift(true, "x");
    }
  });
  
   popX = cp5.addButton("-X")
     .setValue(0)
     .setPosition(5, 310)
     .setSize(45,40)
     .onRelease(new CallbackListener() {
    void controlEvent(CallbackEvent theEvent) {
      frames.get(selectedFrame).shift(false, "x");
      
    }
  });
  
   pushY = cp5.addButton("+Y")
     .setValue(0)
     .setPosition(55, 260)
     .setSize(45,40)
     .onRelease(new CallbackListener() {
    void controlEvent(CallbackEvent theEvent) {
      frames.get(selectedFrame).shift(true, "y");
    }
  });
  
   popY = cp5.addButton("-Y")
     .setValue(0)
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

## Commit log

2022-06-17 notes on which pin used
2022-06-17 WIP: led software
2022-06-18 added KiCad folder
    [3d cube-B_Cu.gbl, 3d cube-B_Mask.gbs, 3d cube-B_Paste.gbp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]
2022-06-19 fixed yellow leds
2022-06-19 wip: added delta time for max frame time and a test script
2022-06-20 added play sequenze button
2022-06-22 rotate with right mouse button, leds in the json files now in the right sequenze
2022-06-22 fixed issues (don't know which, look yourself)
    [main.cpp]
2022-06-22 wip: reverse pins and lines
    [main.cpp]
2022-08-11 added a polling skeleton for pressing buttons
2022-08-15 moved extra files into assets folder
    [3d cube-B_Cu.gbl, 3d cube-B_Mask.gbs, 3d cube-B_Paste.gbp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]
2022-08-16 added todo to buttons, which doesnt work
2022-08-17 added a button test program
2022-08-17 fixed order of pins
    [main.cpp]
2022-08-17 button configuration
2022-08-18 added blink thread for bluetooth pairing led
2022-08-18 reset test improvements and fixed an issue in main program
    [main.cpp]
2022-08-18 removed obsolete buttons program
2022-08-19 added threads to cmake linking
2022-08-19 removed buttons from cmake, as file doesn't exists anymore
2022-08-19 applied reset to main
    [main.cpp]
2022-08-19 updated readme button pins
2022-08-19 wip: button functionality
2022-08-19 button functionality
2022-08-19 moved reset call to each layer
    [main.cpp]
2022-08-20 added button class
2022-08-20 applied button class to main program
2022-08-20 default led-cube configuration path definition
2022-08-22 added const to static Button variable
2022-08-22 fixed bluetooth button crashing program
    [main.cpp]
2022-08-22 print first configuration
2022-08-22 remouve button bounce
2022-08-22 finished button bounce
2022-08-22 added edge case check and removed iterators from next and previous
2022-08-22 fixed next and previous buttons
    [main.cpp]
2022-08-22 undo: fixed next and previous buttons
    [main.cpp]
2022-08-22 undo: undo: fixed next and previous buttons
    [main.cpp]
2022-08-22 fixed previous button
2022-08-22 fixed accidentally decrementing in next
    [main.cpp]
2022-08-22 fixed rotation not working
    [main.cpp]
2022-08-22 parsing layout after each button press
2022-08-23 check if the frames have changed and then quit loop
2022-08-23 uncomment reset call in set_leds, as it didn't cause the weird led behaviour
    [main.cpp]
2022-08-23 added print statement and removed revert
    [main.cpp]
2022-08-23 removed print
2022-08-23 fixed layer 5 being enabled
    [main.cpp]
2022-08-24 git revert to working solution
    [main.cpp]
2022-08-24 special pin only turn off on store (with/ like all the other pins)
2022-08-24 wip: hopefully fix all our layer 1 is on and glows, but 5 also glows problems
    [main.cpp]
2022-08-24 fixed special pin always on
    [main.cpp]
2022-08-24 fixed array indexing last elem with out-of-bounds
    [main.cpp]
2022-08-26 added ScrollView for Frames
2022-08-27 led on/off now functioning
2022-08-27 new frame/delete frame button working
2022-08-28 play button working
2022-08-28 preperation for the open button
2022-08-28 open Json button now working/ version 1.0 working
2022-08-29 wip: removed compilation error
    [main.cpp]
2022-08-29 wip: fix loop performance
    [main.cpp]
2022-08-29 fix orientation to the real cube
    [cube.pde, editor.pde]
2022-08-29 wip: flipped x- and y-axis
    [main.cpp]
2022-08-29 shift buttons working
2022-08-29 shift button behaviour
2022-08-29 finished random and magic button and copy button
2022-08-30 updated user pin usage in table
2022-08-31 changed file system type in mount to vfat, aka usb
2022-09-06 hopefully fixed blink thread not ending bug
    [main.cpp]
2022-09-07 fixed mount path
2022-09-07 fixed button trigger
2022-09-07 fixed buttons not pressed
    [main.cpp]
2022-09-07 fixed blink not stopping, when no mount
2022-09-21 Readme.me Button behaviour
2022-09-21 changed the open and save file buttons to explorer
2022-09-21 fixed inclusion of build files
    [cube.pde, editor.pde]
2022-10-05 renamed KiCad to PCB
    [3d cube-B_Cu.gbl, 3d cube-B_Mask.gbs, 3d cube-B_Paste.gbp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]
2022-10-05 added 3d print files
    [back-side.stl, front-side.stl, left-side.stl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]
2022-10-06 Update assemble.md
    added components, pcb, wire mesh and buttons
